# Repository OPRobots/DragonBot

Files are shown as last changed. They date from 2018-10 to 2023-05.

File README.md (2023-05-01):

# DragonBot
Robot siguelineas con succión centrifuga y STM32F1
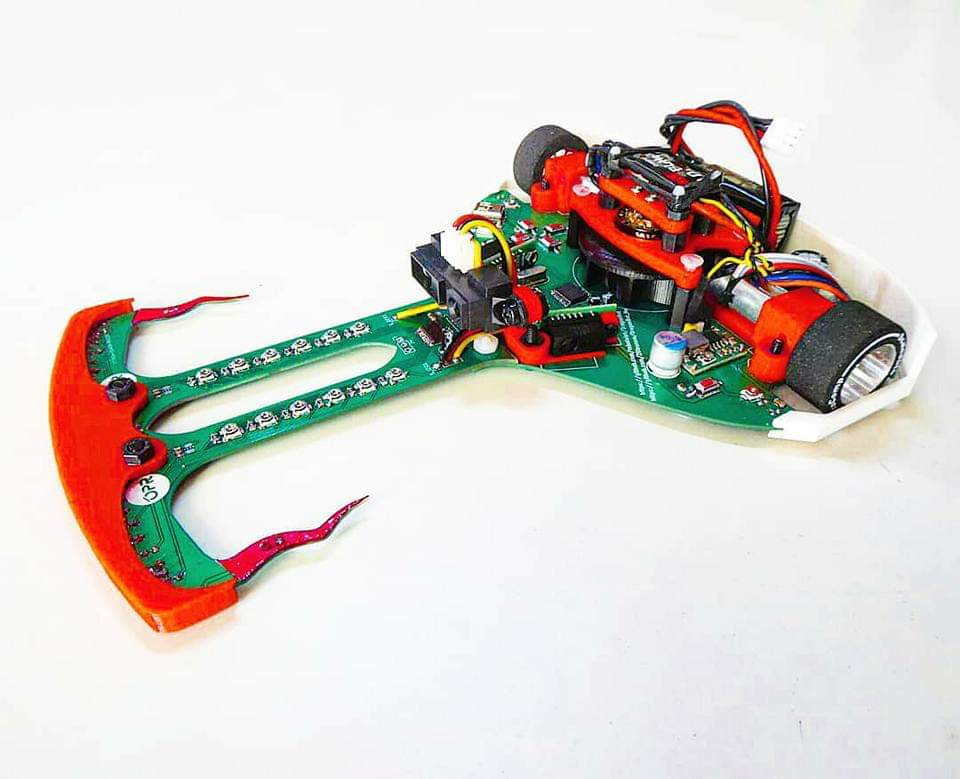
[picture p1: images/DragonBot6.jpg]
DragonBot


## Hardware
- STM32F1 "BluePill"
- Driver de motores TB6612FNG
- 2x Motores Pololu N20 HP @3000rpm
- 1x Motor Brushless Rotorx
- LiPo 2S ~250 mAh
- 12x Sensores QRE1113
- 12x Potenciometros para regular la ganancia de los sensores
- Ruedas Scaleauto Procomp 1
- Chasis de PCB autosoportado con soportes de motores, ventilador y parachoques impresos en PLA
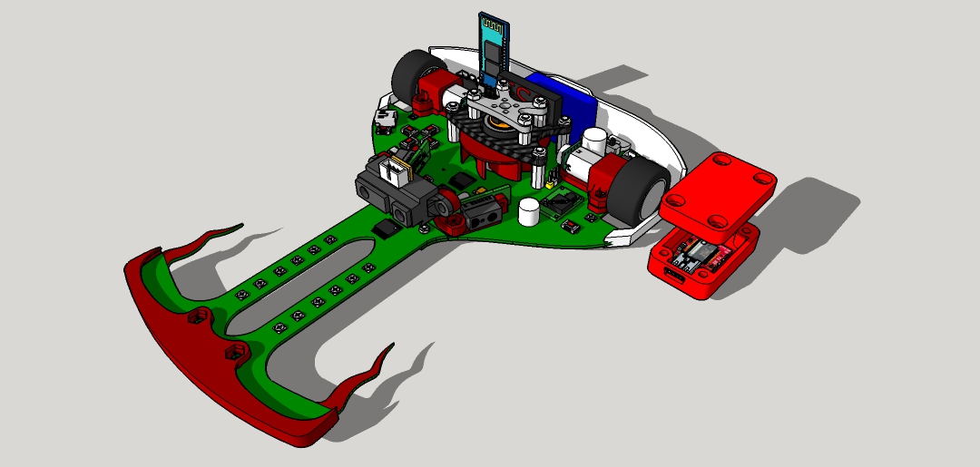
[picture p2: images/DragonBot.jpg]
DragonBot Chasis DragonBot - Chasis


## Software
- Programado con VSCode y PlatformIO
- Funciones de PID y cálculo de posición en la línea
- Disponibles programas para configuración por defecto, coreless y brushless en diferentes ramas secundarias

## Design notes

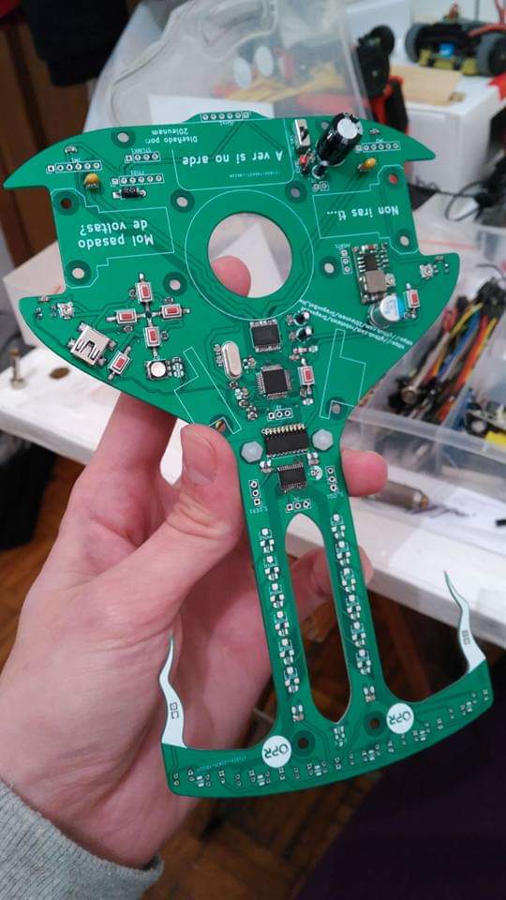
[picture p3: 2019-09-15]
images/DragonBot4.jpg

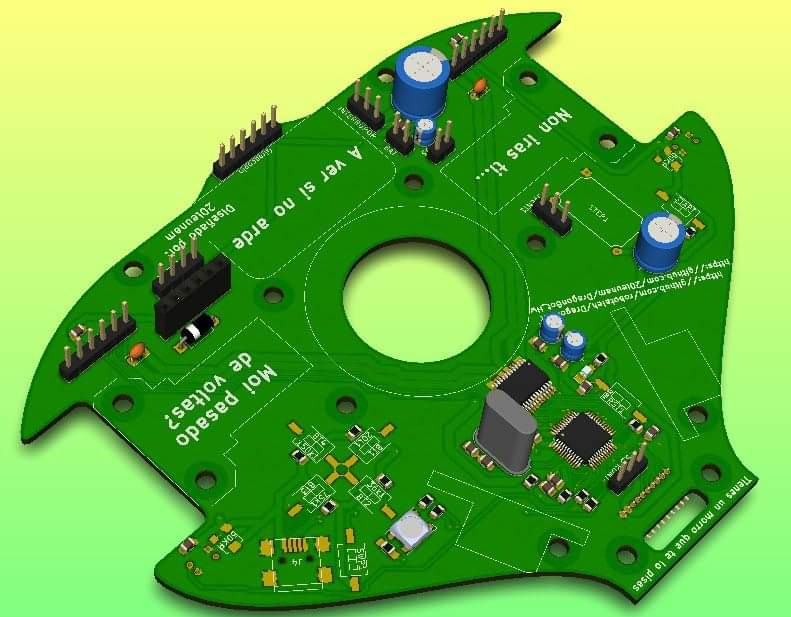
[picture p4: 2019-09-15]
images/DragonBot1.jpg

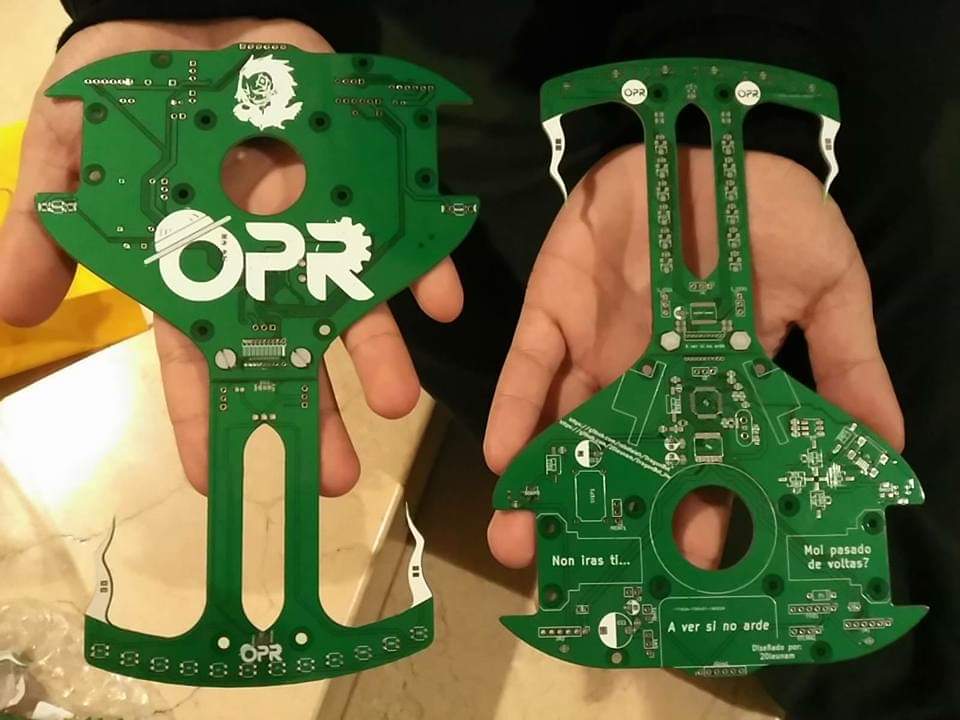
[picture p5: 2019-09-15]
images/DragonBot2.jpg

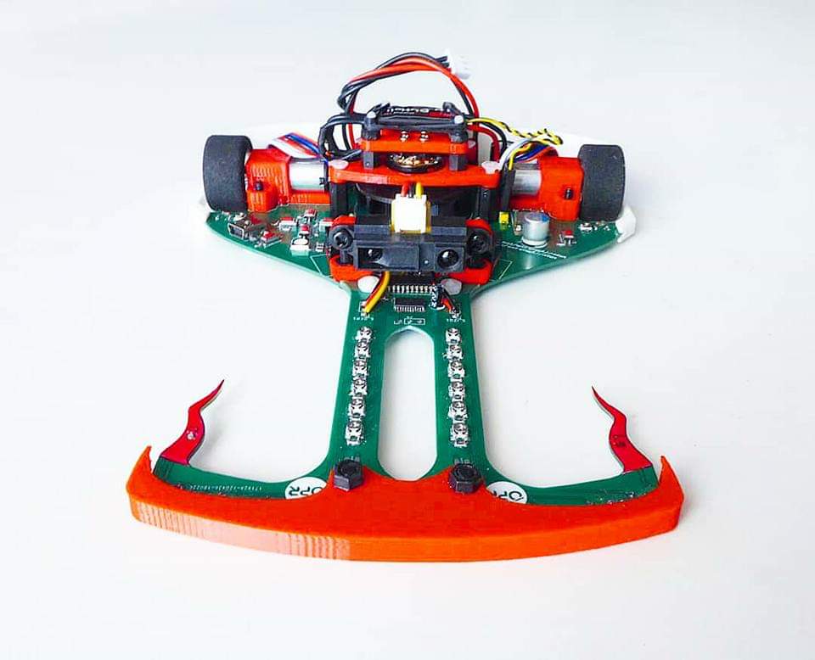
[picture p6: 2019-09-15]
images/DragonBot5.jpg

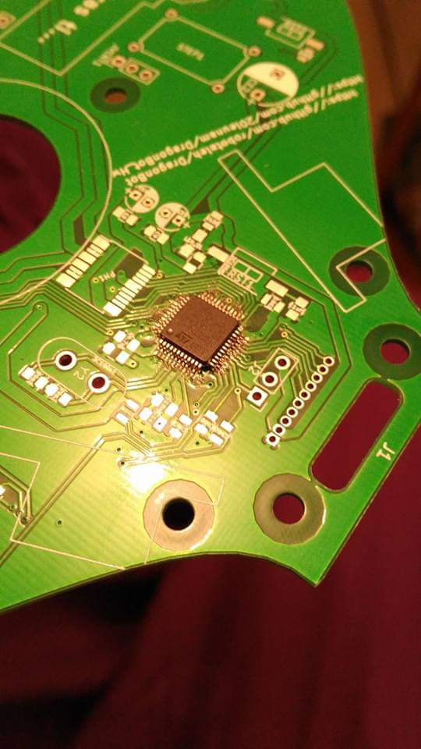
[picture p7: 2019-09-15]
images/DragonBot3.jpg

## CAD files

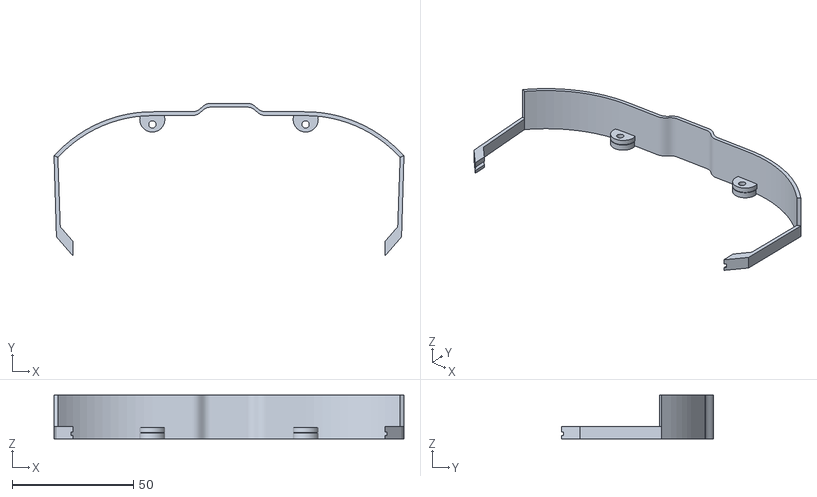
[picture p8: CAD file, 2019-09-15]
3d_model/stl_files/DragonBot_Pantalla_Trasera.stl
144.3 x 62.9 x 18.0

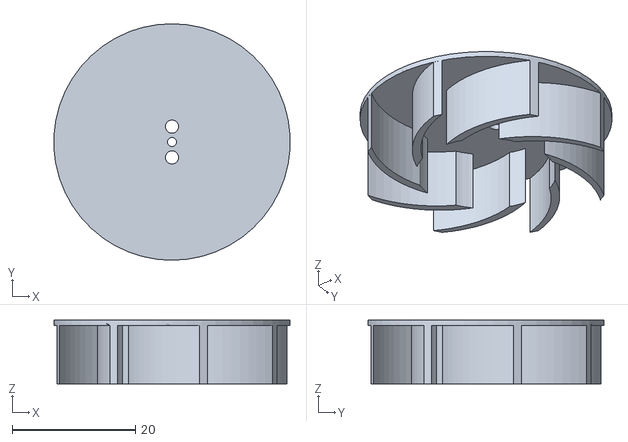
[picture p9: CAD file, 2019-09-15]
3d_model/stl_files/DragonBot_Ventilador_Succion.stl
38.3 x 38.4 x 10.4

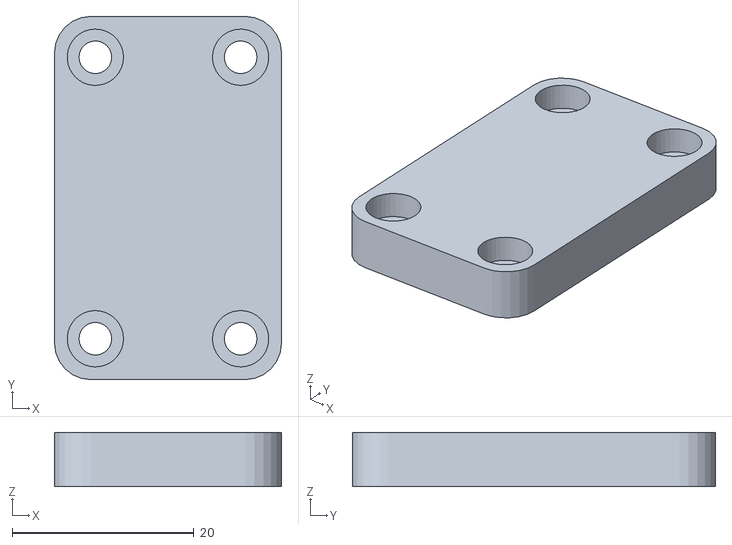
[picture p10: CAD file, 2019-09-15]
3d_model/stl_files/DragonBot_Caja_FTDI_Tapa.stl
25.0 x 40.0 x 6.00

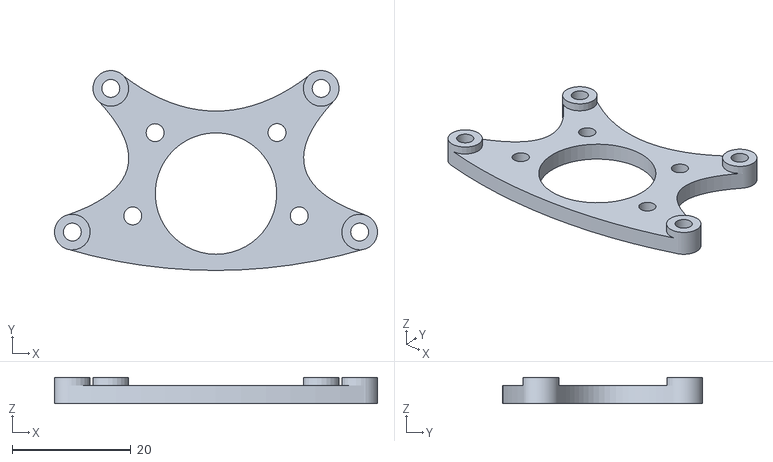
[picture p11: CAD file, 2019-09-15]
3d_model/stl_files/DragonBot_Soporte_Ventilador_Succion_Inferior.stl
54.3 x 33.6 x 4.40

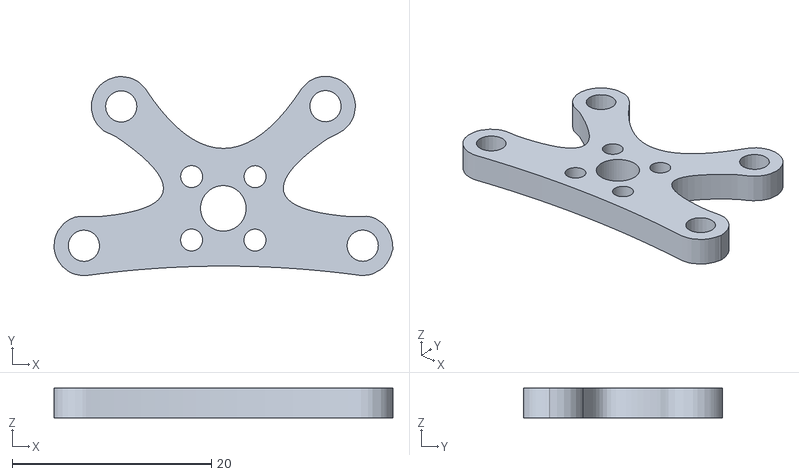
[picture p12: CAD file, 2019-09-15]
3d_model/stl_files/DragonBot_Soporte_Ventilador_Succion_Superior.stl
34.0 x 20.0 x 3.00

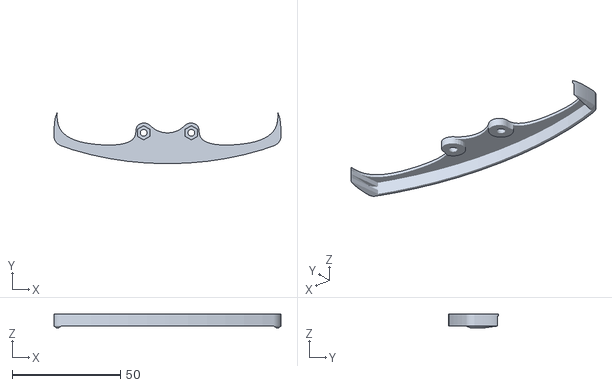
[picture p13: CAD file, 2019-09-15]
3d_model/stl_files/DragonBot_Parachoques_Morro_Ancho.stl
105.0 x 23.2 x 6.70

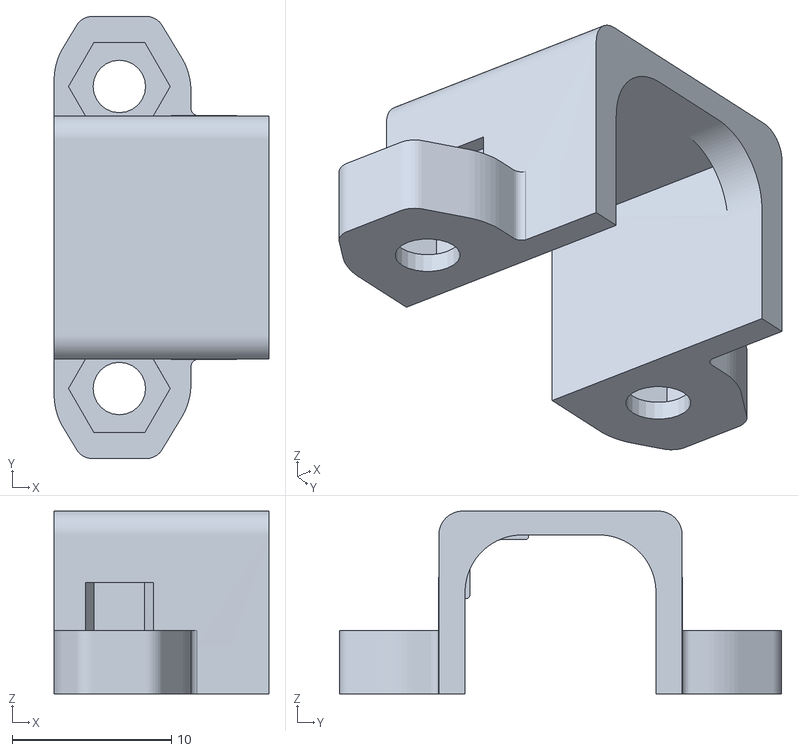
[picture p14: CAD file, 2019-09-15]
3d_model/stl_files/DragonBot_Soporte_Motor_Derecho.stl
13.5 x 27.8 x 11.5

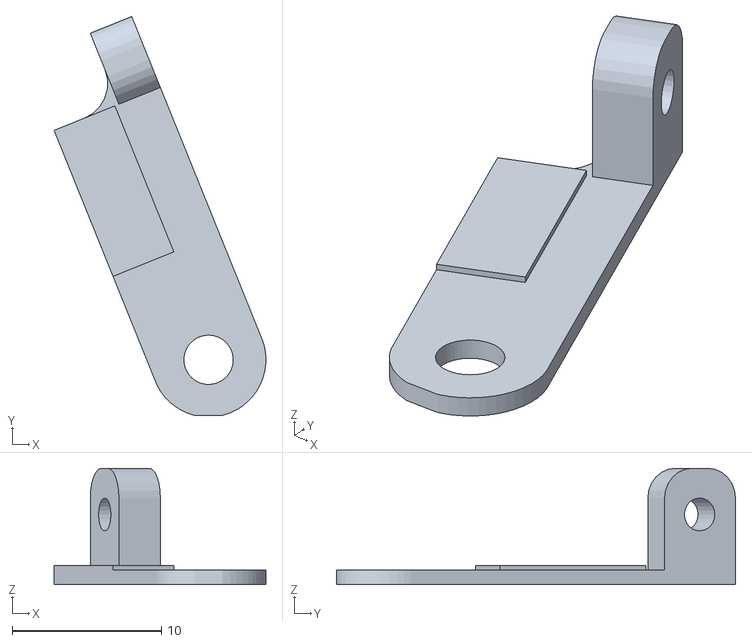
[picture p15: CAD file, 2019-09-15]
3d_model/stl_files/DragonBot_Soporte_Sensor_Lateral_Derecho.stl
14.2 x 26.8 x 7.81

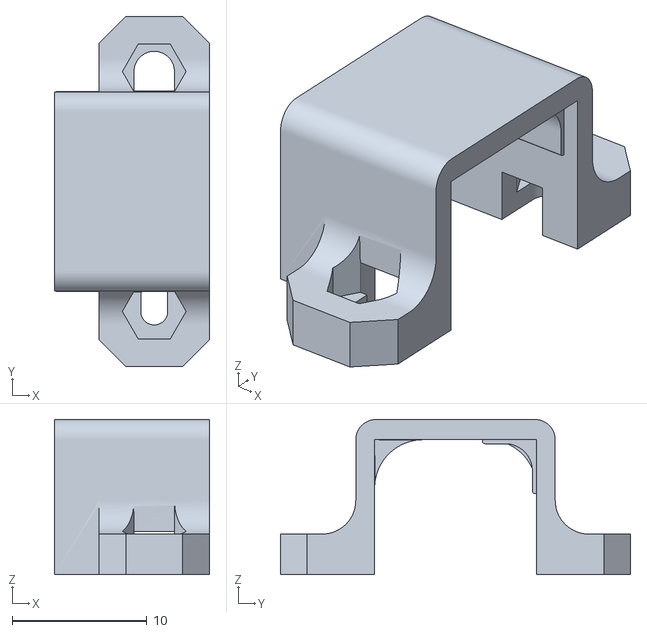
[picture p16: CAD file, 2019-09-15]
3d_model/stl_files/DragonBot_Soporte_Motor_Izquierdo.stl
11.5 x 26.0 x 11.5

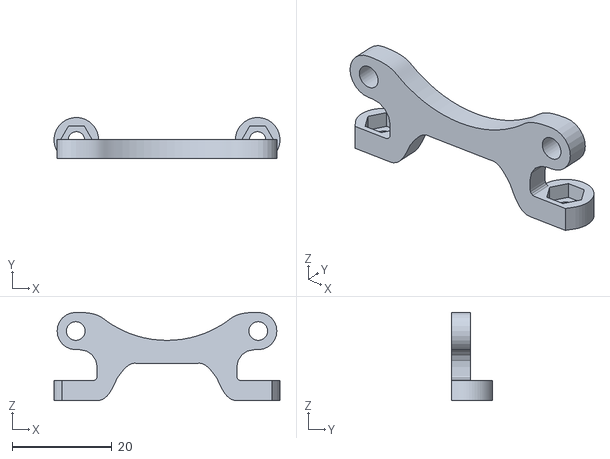
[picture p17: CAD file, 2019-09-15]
3d_model/stl_files/DragonBot_Soporte_Sensor_Frontal.stl
45.4 x 8.23 x 17.7

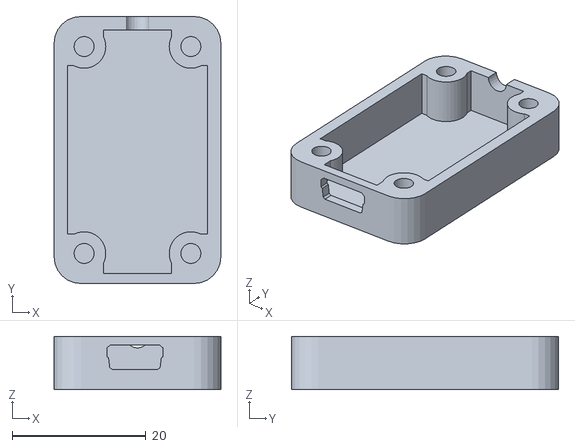
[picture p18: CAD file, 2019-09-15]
3d_model/stl_files/DragonBot_Caja_FTDI_Base.stl
25.0 x 40.0 x 8.00

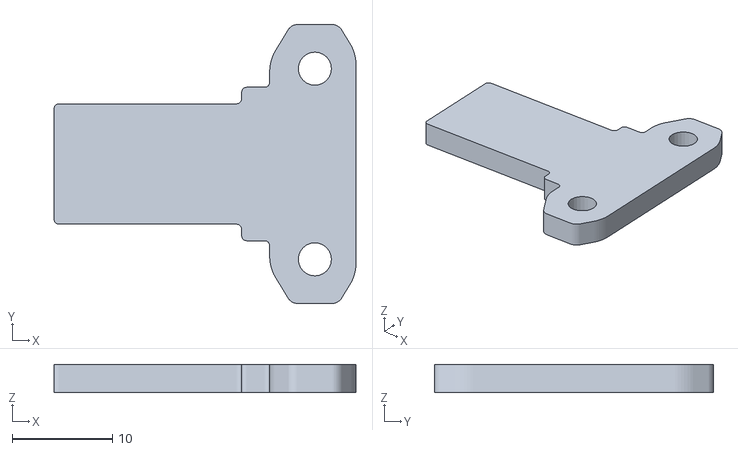
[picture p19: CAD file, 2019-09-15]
3d_model/stl_files/DragonBot_Base_Motores.stl
30.1 x 27.8 x 2.80

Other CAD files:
3d_model/stl_files/DragonBot_Soporte_Sensor_Lateral_Izquierdo.stl

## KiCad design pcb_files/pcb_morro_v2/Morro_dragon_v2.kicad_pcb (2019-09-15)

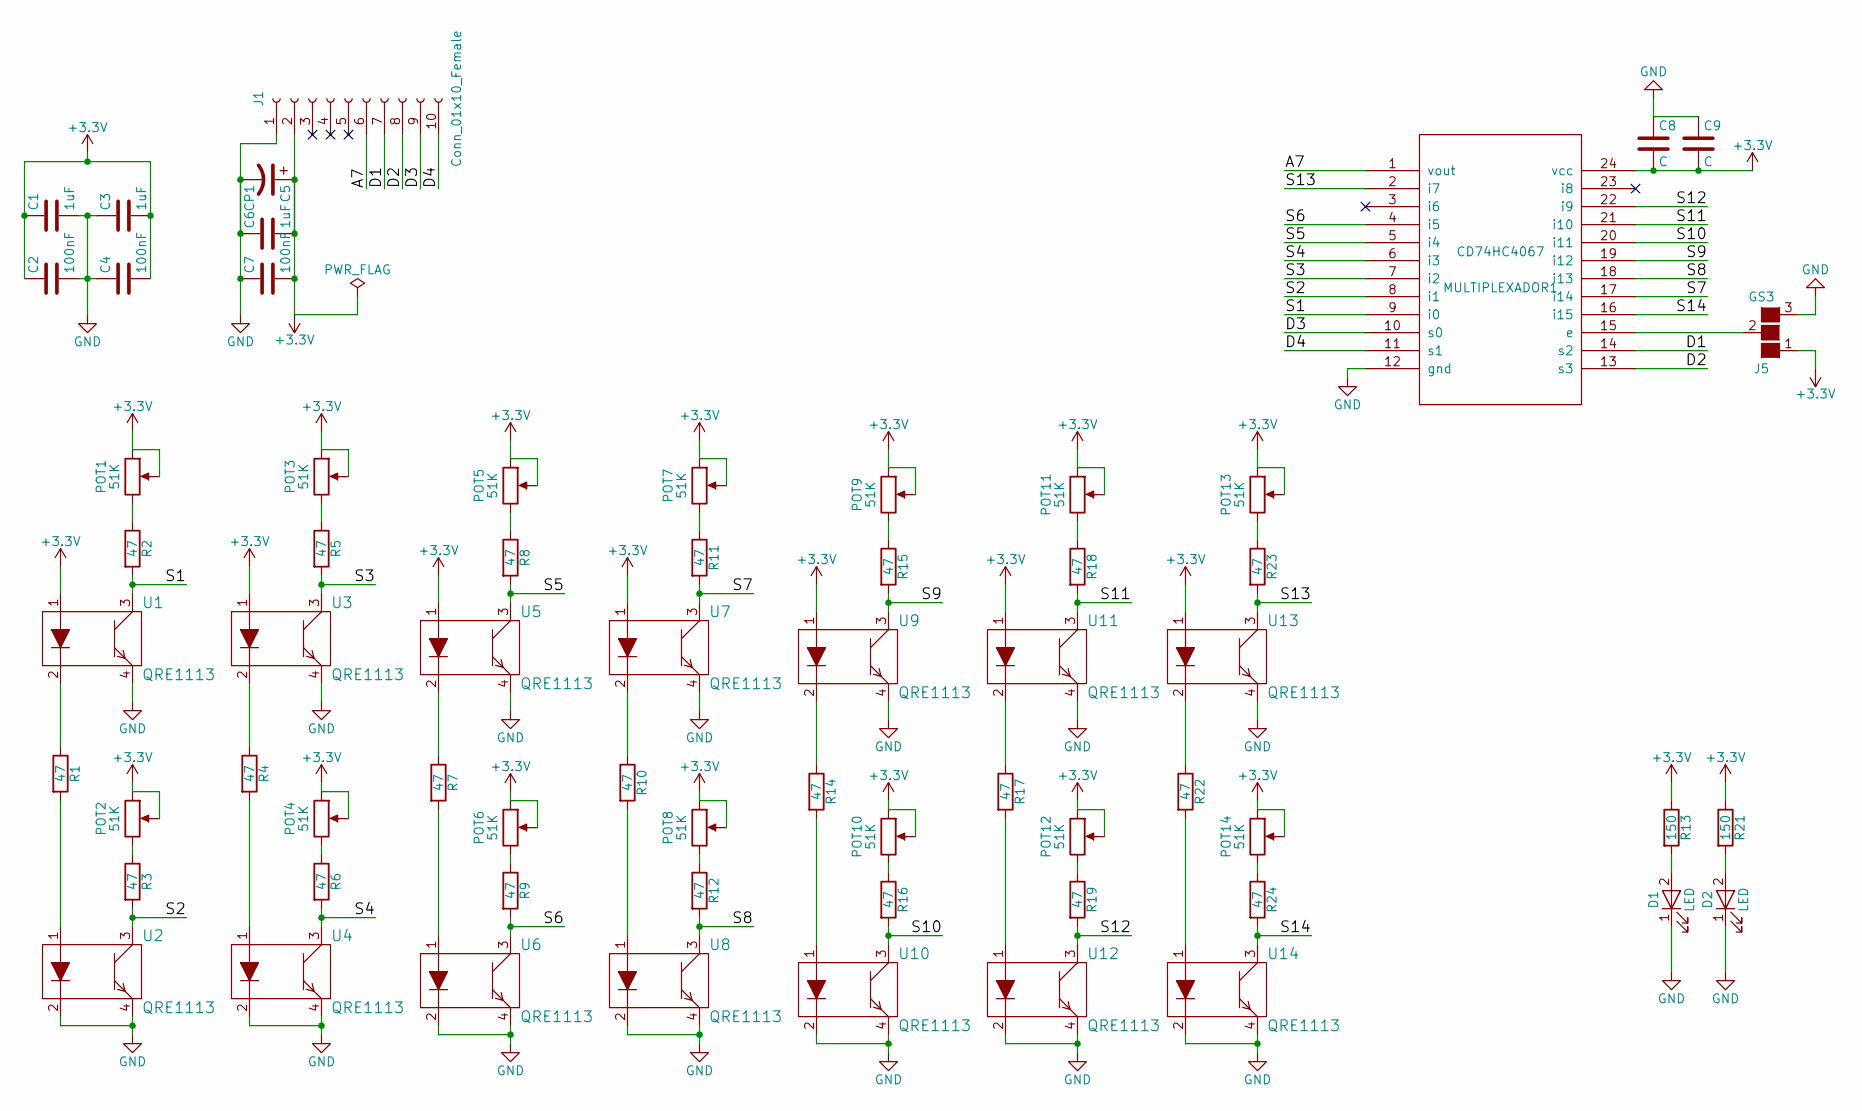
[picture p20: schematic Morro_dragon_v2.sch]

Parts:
C1, C3, C6: 1uF; C_0805
C2, C4, C7: 100nF; C_0805
C5: CP1; CP_Radial_D4.0mm_P1.50mm
C8, C9: C; C_0805
D1, D2: LED; LED_0805
J1: Conn_01x10_Female; Socket_Strip_Straight_1x10_Pitch1.27mm
J5: GS3
MULTIPLEXADOR1: CD74HC4067; TSSOP-24_4.4x7.8mm_Pitch0.65mm
POT1, POT2, POT3, POT4, POT5, POT6, POT7, POT8, POT9, POT10, POT11, POT12, POT13, POT14: 51K; Potentiometer_Trimmer-EVM3E
R1, R2, R3, R4, R5, R6, R7, R8, R9, R10, R11, R12, R14, R15, R16, R17, R18, R19, R22, R23, R24: 47; R_0805
R13, R21: 150; R_0805
U1, U2, U3, U4, U5, U6, U7, U8, U9, U10, U11, U12, U13, U14: QRE1113

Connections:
+3V3: C1.1, C2.1, C3.2, C4.2, C5.1, C6.2, C7.2, C8.2, C9.2, J1.2, J5.1 (G1), MULTIPLEXADOR1.24 (vcc), POT1.1, POT1.2, POT2.1, POT2.2, POT3.1, POT3.2, POT4.1, POT4.2, POT5.1, POT5.2, POT6.1, POT6.2, POT7.1, POT7.2, POT8.1, POT8.2, POT9.1, POT9.2, POT10.1, POT10.2, POT11.1, POT11.2, POT12.1, POT12.2, POT13.1, POT13.2, POT14.1, POT14.2, R13.1, R21.1, U1.1, U3.1, U5.1, U7.1, U9.1, U11.1, U13.1
/A7: J1.6, MULTIPLEXADOR1.1 (vout)
/D1: J1.7, MULTIPLEXADOR1.14 (s2)
/D2: J1.8, MULTIPLEXADOR1.13 (s3)
/D3: J1.9, MULTIPLEXADOR1.10 (s0)
/D4: J1.10, MULTIPLEXADOR1.11 (s1)
/S1: MULTIPLEXADOR1.9 (i0), R2.2, U1.3
/S2: MULTIPLEXADOR1.8 (i1), R3.2, U2.3
/S3: MULTIPLEXADOR1.7 (i2), R5.2, U3.3
/S4: MULTIPLEXADOR1.6 (i3), R6.2, U4.3
/S5: MULTIPLEXADOR1.5 (i4), R8.2, U5.3
/S6: MULTIPLEXADOR1.4 (i5), R9.2, U6.3
/S7: MULTIPLEXADOR1.17 (i14), R11.2, U7.3
/S8: MULTIPLEXADOR1.18 (i13), R12.2, U8.3
/S9: MULTIPLEXADOR1.19 (i12), R15.2, U9.3
/S10: MULTIPLEXADOR1.20 (i11), R16.2, U10.3
/S11: MULTIPLEXADOR1.21 (i10), R18.2, U11.3
/S12: MULTIPLEXADOR1.22 (i9), R19.2, U12.3
/S13: MULTIPLEXADOR1.2 (i7), R23.2, U13.3
/S14: MULTIPLEXADOR1.16 (i15), R24.2, U14.3
GND: C1.2, C2.2, C3.1, C4.1, C5.2, C6.1, C7.1, C8.1, C9.1, D1.1 (K), D2.1 (K), J1.1, J5.3 (G3), MULTIPLEXADOR1.12 (gnd), U1.4, U2.2, U2.4, U3.4, U4.2, U4.4, U5.4, U6.2, U6.4, U7.4, U8.2, U8.4, U9.4, U10.2, U10.4, U11.4, U12.2, U12.4, U13.4, U14.2, U14.4
unnamed: D1.2 (A), R13.2
unnamed: D2.2 (A), R21.2
unnamed: J5.2 (G2), MULTIPLEXADOR1.15 (e)
unnamed: POT1.3, R2.1
unnamed: POT2.3, R3.1
unnamed: POT3.3, R5.1
unnamed: POT4.3, R6.1
unnamed: POT5.3, R8.1
unnamed: POT6.3, R9.1
unnamed: POT7.3, R11.1
unnamed: POT8.3, R12.1
unnamed: POT9.3, R15.1
unnamed: POT10.3, R16.1
unnamed: POT11.3, R18.1
unnamed: POT12.3, R19.1
unnamed: POT13.3, R23.1
unnamed: POT14.3, R24.1
unnamed: R1.1, U1.2
unnamed: R1.2, U2.1
unnamed: R4.1, U3.2
unnamed: R4.2, U4.1
unnamed: R7.1, U5.2
unnamed: R7.2, U6.1
unnamed: R10.1, U7.2
unnamed: R10.2, U8.1
unnamed: R14.1, U9.2
unnamed: R14.2, U10.1
unnamed: R17.1, U11.2
unnamed: R17.2, U12.1
unnamed: R22.1, U13.2
unnamed: R22.2, U14.1

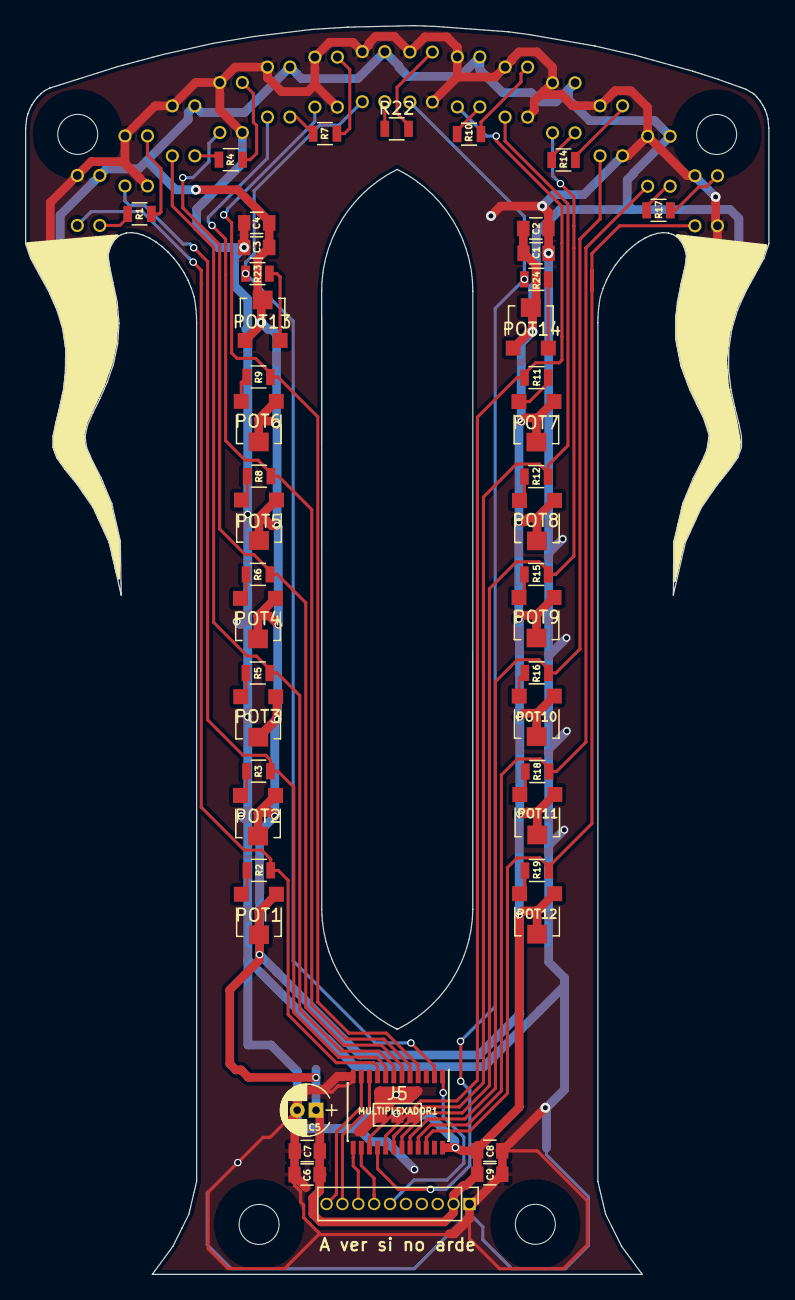
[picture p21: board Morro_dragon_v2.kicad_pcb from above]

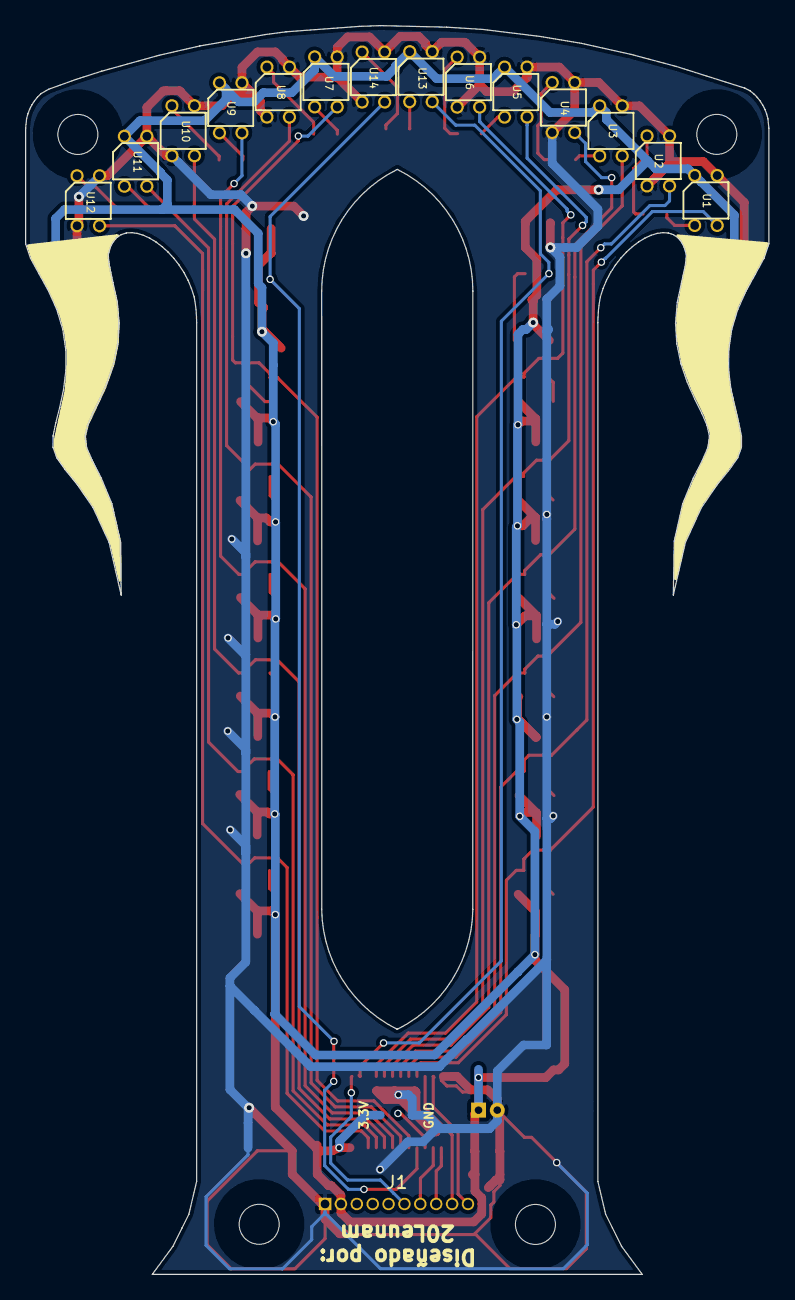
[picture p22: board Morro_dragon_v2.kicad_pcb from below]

Board: 2 copper layers, 59.4 x 99.9 mm, 65 parts (16 on the bottom side), 52 nets.

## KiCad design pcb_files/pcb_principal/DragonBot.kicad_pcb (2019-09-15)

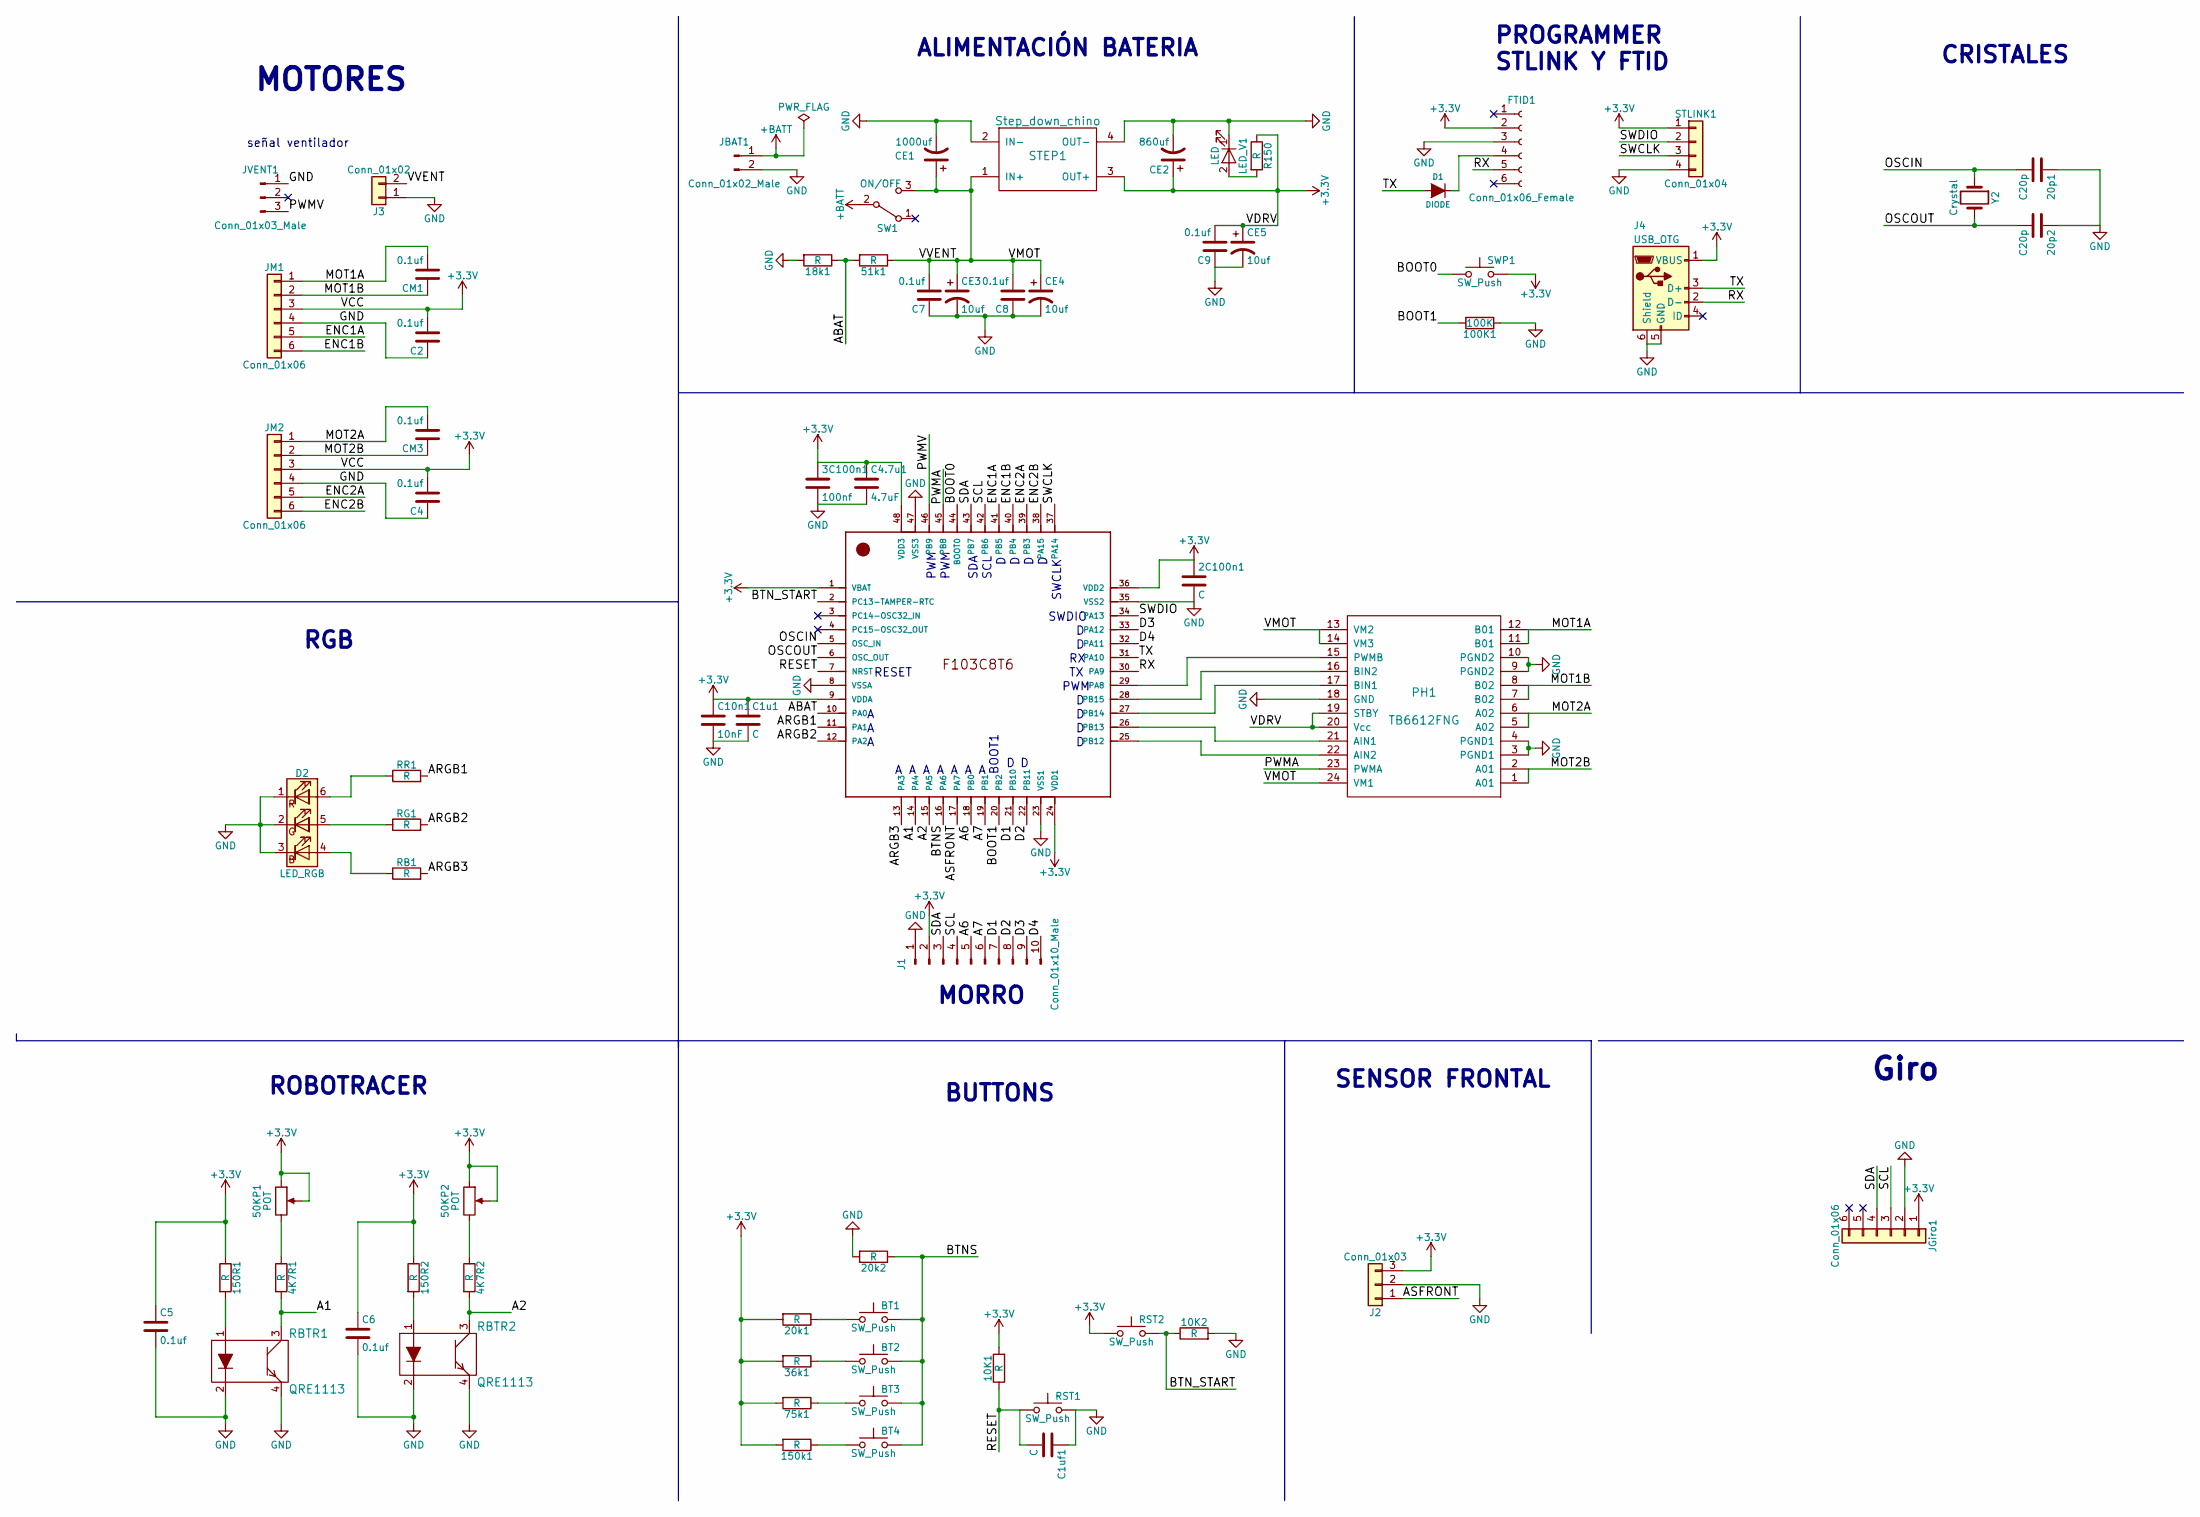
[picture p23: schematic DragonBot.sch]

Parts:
2C100n1: C; C_0805
3C100n1: 100nf; C_0805
4K7R1, 4K7R2, 10K1, 10K2, 18k1, 20k1, 20k2, 36k1, 51k1, 75k1, 150R1, 150R2, 150k1: R; R_0805
20p1, 20p2: C20p; C_0805
50KP1, 50KP2: POT; Potentiometer_Trimmer-EVM3E
100K1: 100K; R_0805
BT1, BT2, BT3, BT4: SW_Push; SW_DIP_x1_W8.61mm_Slide_LowProfile
C1u1, C1uf1: C; C_0805
C2, C4, C5, C6, C7, C8, C9: 0.1uf; C_0805
C4.7u1: 4.7uF; C_0805
C10n1: 10nF; C_0805
CE1: 1000uf; CP_Radial_D10.0mm_P7.50mm
CE2: 860uf; CP_Radial_D8.0mm_P5.00mm
CE3, CE4, CE5: 10uf; CP_Radial_D4.0mm_P2.00mm
CM1, CM3: 0.1uf; C_Disc_D3.4mm_W2.1mm_P2.50mm
D1: DIODE; D_A-405_P7.62mm_Horizontal
D2: LED_RGB; LED_RGB_5050-6
FTID1: Conn_01x06_Female; Socket_Strip_Straight_1x06_Pitch2.54mm
J1: Conn_01x10_Male; Pin_Header_Angled_1x10_Pitch1.27mm
J2: Conn_01x03; Pin_Header_Straight_1x03_Pitch2.54mm
J3: Conn_01x02; Pin_Header_Straight_1x02_Pitch2.54mm
J4: USB_OTG; USB_Mini-B
JBAT1: Conn_01x02_Male; Pin_Header_Straight_1x02_Pitch2.54mm
JGiro1: Conn_01x06; Pin_Header_Straight_1x06_Pitch2.54mm
JM1, JM2: Conn_01x06; Pin_Header_Straight_1x06_Pitch2.54mm
JVENT1: Conn_01x03_Male; Pin_Header_Straight_1x03_Pitch2.54mm
LED_V1: LED; LED_0805_HandSoldering
PH1: TB6612FNG; SSOP-24_5.3x8.2mm_Pitch0.65mm
R150: R; R_0805
RB1: R; R_0805
RBTR1, RBTR2: QRE1113
RG1: R; R_0805
RR1: R; R_0805
RST1, RST2: SW_Push; SW_DIP_x1_W8.61mm_Slide_LowProfile
STEP1: Step_down_chino
STLINK1: Conn_01x04; Pin_Header_Straight_1x04_Pitch2.54mm
SW1: ON/OFF; Pin_Header_Straight_1x03_Pitch2.54mm
SWP1: SW_Push; SW_DIP_x1_W8.61mm_Slide_LowProfile
U1: STM32F103C8T6; LQFP-48_7x7mm_Pitch0.5mm; Digi-Key_Part_Number 497-6063-ND
Y2: Crystal; Crystal_HC50_Vertical

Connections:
+3V3: 2C100n1.1, 3C100n1.1, 10K1.2, 20k1.2, 36k1.2, 50KP1.1, 50KP1.2, 50KP2.1, 50KP2.2, 75k1.2, 150R1.1, 150R2.1, 150k1.2, C1u1.1, C2.2, C4.2, C4.7u1.1, C5.1, C6.1, C9.2, C10n1.1, CE2.1, CE5.1, FTID1.2, J1.2, J2.3, J4.1 (VBUS), JGiro1.1, JM1.3, JM2.3, PH1.19 (STBY), PH1.20 (Vcc), R150.1, RST2.1, STEP1.3 (OUT+), STLINK1.1, SWP1.2, U1.1 (VBAT), U1.9 (VDDA), U1.24 (VDD1), U1.36 (VDD2), U1.48 (VDD3)
+BATT: JBAT1.1, SW1.2 (B)
/A1: 4K7R1.2, RBTR1.3, U1.14 (PA4)
/A2: 4K7R2.2, RBTR2.3, U1.15 (PA5)
/A6: J1.5, U1.18 (PB0)
/A7: J1.6, U1.19 (PB1)
/ABAT: 18k1.1, 51k1.2, U1.10 (PA0)
/ARGB1: RR1.2, U1.11 (PA1)
/ARGB2: RG1.2, U1.12 (PA2)
/ARGB3: RB1.2, U1.13 (PA3)
/ASFRONT: J2.1, U1.17 (PA7)
/BOOT0: SWP1.1, U1.44 (BOOT0)
/BOOT1: 100K1.2, U1.20 (PB2)
/BTNS: 20k2.1, BT1.2, BT2.2, BT3.2, BT4.2, U1.16 (PA6)
/BTN_START: 10K2.1, RST2.2, U1.2 (PC13-TAMPER-RTC)
/D1: J1.7, U1.21 (PB10)
/D2: J1.8, U1.22 (PB11)
/D3: J1.9, U1.33 (PA12)
/D4: J1.10, U1.32 (PA11)
/ENC1A: JM1.5, U1.41 (PB5)
/ENC1B: JM1.6, U1.40 (PB4)
/ENC2A: JM2.5, U1.39 (PB3)
/ENC2B: JM2.6, U1.38 (PA15)
/MOT1A: CM1.2, JM1.1, PH1.11 (B01), PH1.12 (B01)
/MOT1B: CM1.1, JM1.2, PH1.7 (B02), PH1.8 (B02)
/MOT2A: CM3.2, JM2.1, PH1.5 (A02), PH1.6 (A02)
/MOT2B: CM3.1, JM2.2, PH1.1 (A01), PH1.2 (A01)
/OSCIN: 20p1.2, U1.5 (OSC_IN), Y2.1
/OSCOUT: 20p2.2, U1.6 (OSC_OUT), Y2.2
/PWMA: PH1.23 (PWMA), U1.45 (PB8)
/PWMV: JVENT1.3, U1.46 (PB9)
/RESET: 10K1.1, C1uf1.2, RST1.1, U1.7 (NRST)
/RX: FTID1.5, J4.2 (D-), U1.30 (PA9)
/SCL: J1.4, JGiro1.3, U1.42 (PB6)
/SDA: J1.3, JGiro1.4, U1.43 (PB7)
/SWCLK: STLINK1.3, U1.37 (PA14)
/SWDIO: STLINK1.2, U1.34 (PA13)
/TX: D1.1 (A), J4.3 (D+), U1.31 (PA10)
/VMOT: 51k1.1, C7.2, C8.2, CE1.1, CE3.1, CE4.1, J3.2, PH1.13 (VM2), PH1.14 (VM3), PH1.24 (VM1), STEP1.1 (IN+), SW1.3 (C)
GND: 2C100n1.2, 3C100n1.2, 10K2.2, 18k1.2, 20k2.2, 20p1.1, 20p2.1, 100K1.1, C1u1.2, C1uf1.1, C2.1, C4.1, C4.7u1.2, C5.2, C6.2, C7.1, C8.1, C9.1, C10n1.2, CE1.2, CE2.2, CE3.2, CE4.2, CE5.2, D2.1 (RK), D2.2 (GK), D2.3 (BK), FTID1.3, J1.1, J2.2, J3.1, J4.5 (GND), J4.6 (Shield), JBAT1.2, JGiro1.2, JM1.4, JM2.4, JVENT1.1, LED_V1.1 (K), PH1.3 (PGND1), PH1.4 (PGND1), PH1.9 (PGND2), PH1.10 (PGND2), PH1.18 (GND), RBTR1.2, RBTR1.4, RBTR2.2, RBTR2.4, RST1.2, STEP1.2 (IN-), STEP1.4 (OUT-), STLINK1.4, U1.8 (VSSA), U1.23 (VSS1), U1.35 (VSS2), U1.47 (VSS3)
unnamed: 4K7R1.1, 50KP1.3
unnamed: 4K7R2.1, 50KP2.3
unnamed: 20k1.1, BT1.1
unnamed: 36k1.1, BT2.1
unnamed: 75k1.1, BT3.1
unnamed: 150R1.2, RBTR1.1
unnamed: 150R2.2, RBTR2.1
unnamed: 150k1.1, BT4.1
unnamed: D1.2 (K), FTID1.4
unnamed: D2.4 (BA), RB1.1
unnamed: D2.5 (GA), RG1.1
unnamed: D2.6 (RA), RR1.1
unnamed: LED_V1.2 (A), R150.2
unnamed: PH1.15 (PWMB), U1.29 (PA8)
unnamed: PH1.16 (BIN2), U1.28 (PB15)
unnamed: PH1.17 (BIN1), U1.27 (PB14)
unnamed: PH1.21 (AIN1), U1.26 (PB13)
unnamed: PH1.22 (AIN2), U1.25 (PB12)

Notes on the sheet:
RGB
ROBOTRACER
BUTTONS
MORRO
PROGRAMMER STLINK Y FTID
MOTORES
ALIMENTACIÓN BATERIA
CRISTALES
señal ventilador
SENSOR FRONTAL
SWDIO
RESET
BOOT1
PWM
SDA
SCL
SWCLK
Giro

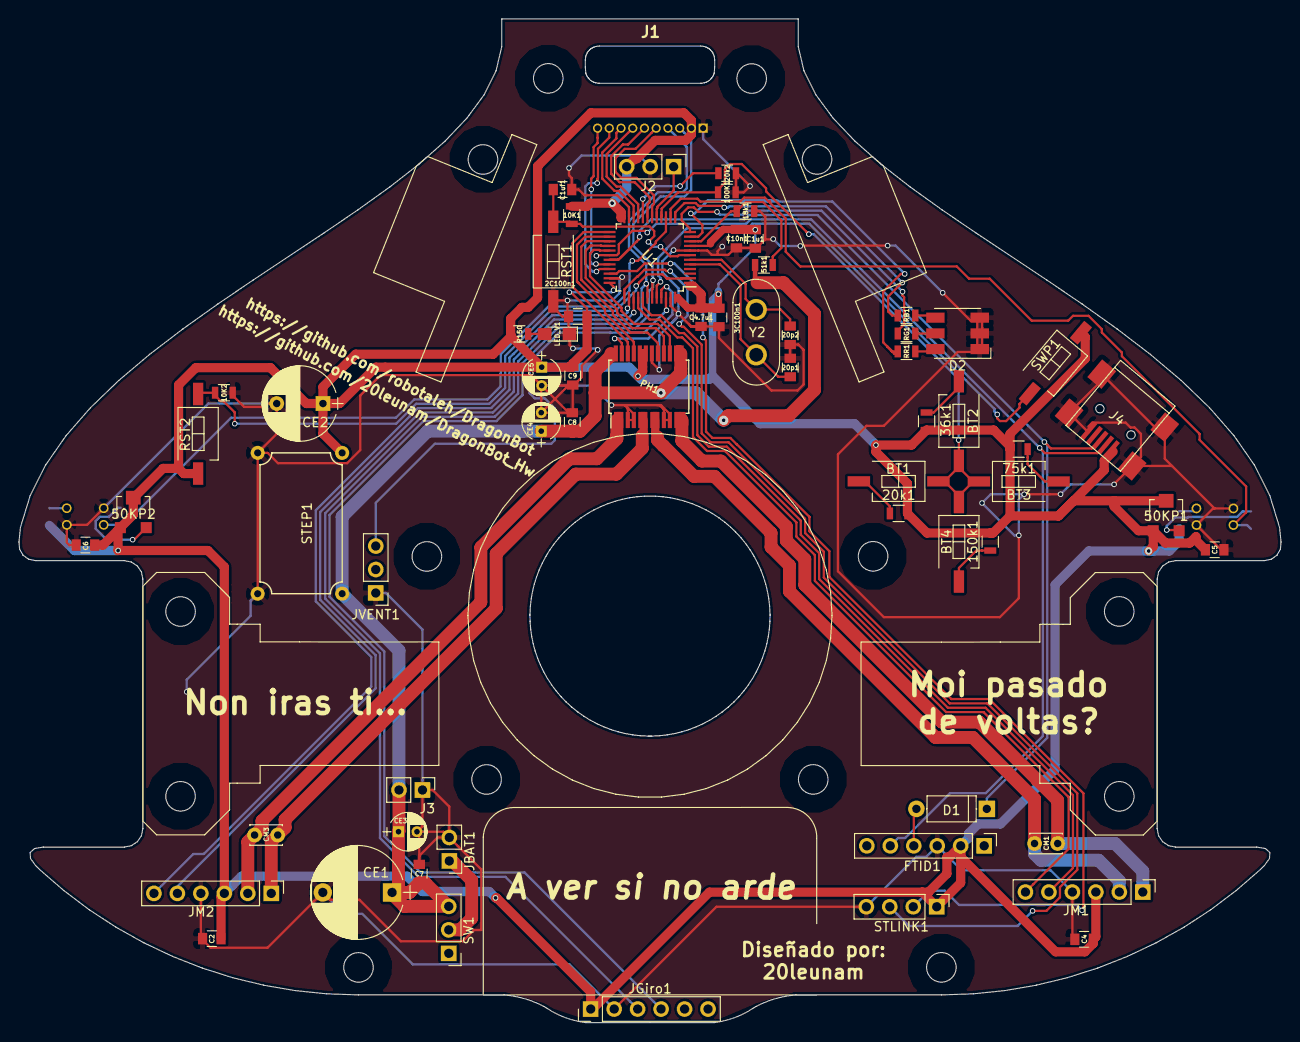
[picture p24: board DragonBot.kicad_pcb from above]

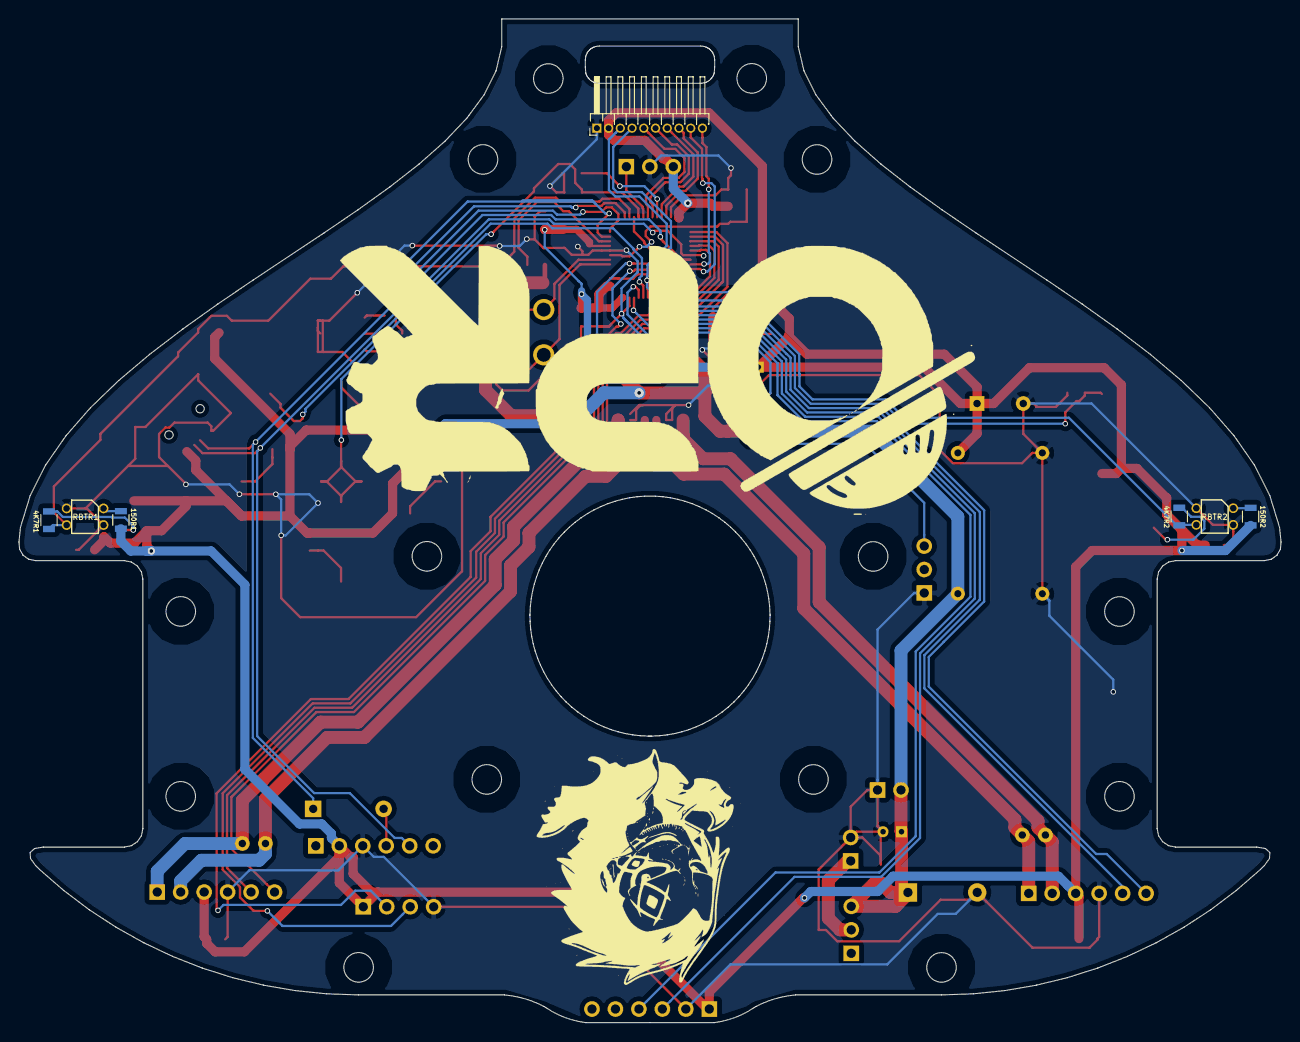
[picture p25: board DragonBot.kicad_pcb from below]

Board: 2 copper layers, 136.6 x 108.6 mm, 70 parts (7 on the bottom side), 58 nets.

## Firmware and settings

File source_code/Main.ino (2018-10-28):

//////////////////////////
// INCLUDE de LIBRERIAS //
//////////////////////////
/**
 * Calibración del PID desde la APP android PIDfromBT
 * https://github.com/robotaleh/PIDfromBT
 */
#include <Filter.h>
#include <MegunoLink.h>
#include <PIDfromBT.h>
#include <Wire.h>

////////////////////////
// SELECTOR DE ROBOT  //
////////////////////////
// #define DRAGON_A 1
#define DRAGON_B 1

#define MORRO_ANCHO 1
// #define MORRO_ESTRECHO 1

////////////
// MODOS  //
////////////
#define MODO_LINEA 1

#define LINEA_NEGRA 1
#define LINEA_BLANCA 2

#define LIPO_2S 1
#define LIPO_3S 2

///////////////////
// CONFIGURACION //
///////////////////
#define MILLIS_INICIO 2000
#define PISTA MODO_LINEA
#define LINEA LINEA_NEGRA
#define LIPO LIPO_3S
#define TIEMPO_CALIBRADO 2500
#define CALIBRAR_SENSORES true

//////////////
// SENSORES //
//////////////
#define TIEMPO_SIN_PISTA 200

#ifdef MORRO_ANCHO
#define NUMERO_SENSORES 8
#define SENSOR_1 0
#define SENSOR_2 1
#define SENSOR_3 2
#define SENSOR_4 3
#define SENSOR_5 4
#define SENSOR_6 5
#define SENSOR_7 14
#define SENSOR_8 13
#define SENSOR_9 12
#define SENSOR_10 11
#define SENSOR_11 10
#define SENSOR_12 9

#elif MORRO_ESTRECHO
#define NUMERO_SENSORES 14
#define SENSOR_1 0
#define SENSOR_2 1
#define SENSOR_3 2
#define SENSOR_4 3
#define SENSOR_5 4
#define SENSOR_6 5
#define SENSOR_7 7
#define SENSOR_8 15
#define SENSOR_9 14
#define SENSOR_10 13
#define SENSOR_11 12
#define SENSOR_12 11
#define SENSOR_13 10
#define SENSOR_14 9
#endif
#define SENSOR_ROBOTRACER_DERECHO PA4
#define SENSOR_ROBOTRACER_IZQUIERDO PA5

#define CALIBRADO_MAXIMO_SENSORES_LINEA 4000
#define CALIBRADO_MINIMO_SENSORES_LINEA 0
#define SATURACION_MAXIMO_SENSORES_LINEA 3000
#define SATURACION_MINIMO_SENSORES_LINEA 1000

///////////////////
// MULTIPLEXADOR //
///////////////////
#define MUX_LECTURA PB1
#define MUX_CANAL_0 PA12
#define MUX_CANAL_1 PA11
#define MUX_CANAL_2 PB10
#define MUX_CANAL_3 PB11

/////////////
// MOTORES //
/////////////
#ifdef DRAGON_A
#define MOTOR_DERECHO_ADELANTE PB15
#define MOTOR_DERECHO_ATRAS PB14
#define MOTOR_IZQUIERDO_ADELANTE PB13
#define MOTOR_IZQUIERDO_ATRAS PB12
#endif

#ifdef DRAGON_B
#define MOTOR_DERECHO_ADELANTE PB14
#define MOTOR_DERECHO_ATRAS PB15
#define MOTOR_IZQUIERDO_ADELANTE PB13
#define MOTOR_IZQUIERDO_ATRAS PB12
#endif

#define MOTOR_DERECHO_PWM PA8
#define MOTOR_IZQUIERDO_PWM PB8
#define MOTOR_SUCCION PB9

//////////////
// ENCODERS //
//////////////
#define MOTOR_DERECHO_ENCODER_A PB5
#define MOTOR_DERECHO_ENCODER_B PB4
#define MOTOR_IZQUIERDO_ENCODER_A PA15
#define MOTOR_IZQUIERDO_ENCODER_B PB3

//////////////
// MPU9250  //
//////////////
#define MPU9250_ADDRESS 0x68

#define GYRO_FULL_SCALE_250_DPS 0x00
#define GYRO_FULL_SCALE_500_DPS 0x08
#define GYRO_FULL_SCALE_1000_DPS 0x10
#define GYRO_FULL_SCALE_2000_DPS 0x18

#define ACC_FULL_SCALE_2_G 0x00
#define ACC_FULL_SCALE_4_G 0x08
#define ACC_FULL_SCALE_8_G 0x10
#define ACC_FULL_SCALE_16_G 0x18

//////////
// LEDS //
//////////
#define RED_RGB_R PA1
#define RED_RGB_G PA2
#define RED_RGB_B PA3

///////////////////////////////////
// VARIABLES DE CONTROL DE LEDS  //
///////////////////////////////////
int colorRGB[] = {255, 0, 0};
int colorDesc = 0;
int colorAsc = 1;
long ultimoCambioRGB = 0;

/////////////
// BOTONES //
/////////////
#define BTN PC13
#define BTN_CRUCETA PA6

//////////
// MISC //
//////////
#define NIVEL_BATERIA PA0

///////////////
// VARIABLES //
///////////////
float anguloGiro = 0;
float anguloGiroR = 0;
float velocidadW = 0;
float velocidadMs = 0;
float posXm = 0;
float posYm = 0;
int velocidad = 0;
float velocidadMsIdeal = 0;
float velocidadMsIdealBase = 0;
int velocidadSuccion = 0;
int velocidadSuccionBase = 50;
int velocidadMaxima = 255;
long ultimaLinea = 0;
long ultimaBateria = 0;
bool avisoBateria = false;
int intervaloAvisoBateria = 500;
long millisInitESC = -1;
bool ESCIniciado = false;

//////////////////////////
// VARIABLES DE CONTROL //
//////////////////////////
int posicionActual = 0;
int posicionIdeal = 0;
int posicionIdealObjetivo;
float errorAnterior = 0;
float integralErrores = 0;
float kp;
float ki;
float kd;
float kpVelocidad = 5;
float kdVelocidad = 10;
float ultimoErrorVelocidad = 0;
int correccion = 0;

////////////////////////////
// VARIABLES DE ENCODERS  //
////////////////////////////
#define ENCODER_PPR 119
#define RUEDAS_RADIO 0.01275
float ticksMm = 1.444f;
long ticksDerechoAnteriores = 0;
long ticksIzquierdoAnteriores = 0;
volatile long ticksDerecho = 0;
volatile long ticksIzquierdo = 0;

///////////////////////////
// VARIABLES DE SENSORES //
///////////////////////////
int valorSaturacionBajo;
int valorSaturacionAlto;
#ifdef MORRO_ANCHO
int pinesSensores[] = {/* SENSOR_1, SENSOR_2, */ SENSOR_3, SENSOR_4, SENSOR_5, SENSOR_6, SENSOR_7, SENSOR_8, SENSOR_9, SENSOR_10/* , SENSOR_11, SENSOR_12 */};
int valoresSensores[] = {0, 0, 0, 0, 0, 0, 0, 0, 0, 0, 0, 0};
int valoresSensoresRaw[] = {0, 0, 0, 0, 0, 0, 0, 0, 0, 0, 0, 0};
#elif MORRO_ESTRECHO
int pinesSensores[] = {SENSOR_1, SENSOR_2, SENSOR_3, SENSOR_4, SENSOR_5, SENSOR_6, SENSOR_7, SENSOR_8, SENSOR_9, SENSOR_10, SENSOR_11, SENSOR_12, SENSOR_13, SENSOR_14};
int valoresSensores[] = {0, 0, 0, 0, 0, 0, 0, 0, 0, 0, 0, 0, 0, 0};
int valoresSensoresRaw[] = {0, 0, 0, 0, 0, 0, 0, 0, 0, 0, 0, 0, 0, 0};
#endif
int posicionMaxima = 6500;
int posicionMinima = -6500;

///////////////////////////////
// VARIABLES DE CALIBRACIÓN  //
///////////////////////////////
#ifdef MORRO_ANCHO
int valoresCalibracionMinimos[] = {4096, 4096, 4096, 4096, 4096, 4096, 4096, 4096, 4096, 4096, 4096, 4096};
int valoresCalibracionMaximos[] = {0, 0, 0, 0, 0, 0, 0, 0, 0, 0, 0, 0};
#elif MORRO_ESTRECHO
int valoresCalibracionMinimos[] = {4096, 4096, 4096, 4096, 4096, 4096, 4096, 4096, 4096, 4096, 4096, 4096, 4096, 4096};
int valoresCalibracionMaximos[] = {0, 0, 0, 0, 0, 0, 0, 0, 0, 0, 0, 0, 0, 0};
#endif
int umbralesCalibracionSensores[NUMERO_SENSORES];
int valorCalibradoMaximo;
int valorCalibradoMinimo;

///////////////////////////////
// VARIABLES DE COMPETICIÓN  //
///////////////////////////////
bool competicionIniciada = false;

/////////////////////////////////////////
// VARIABLES DE MENÚ DE CONFIGURACIÓN  //
/////////////////////////////////////////
#define NUMERO_COMBINACIONES 10
#define CRUCETA_ARRIBA 1460
#define CRUCETA_ABAJO 475
#define CRUCETA_DERECHA 860
#define CRUCETA_IZQUIERDA 2040
#define CRUCETA_ARRIBA_ABAJO 1670
#define CRUCETA_DERECHA_IZQUIERDA 2280
#define CRUCETA_ARRIBA_DERECHA 1840
#define CRUCETA_DERECHA_ABAJO 1160
#define CRUCETA_ABAJO_IZQUIERDA 2170
#define CRUCETA_IZQUIERDA_ARRIBA 2490
int crucetaCombinaciones[] = {CRUCETA_ARRIBA,
                              CRUCETA_ABAJO,
                              CRUCETA_DERECHA,
                              CRUCETA_IZQUIERDA,
                              CRUCETA_ARRIBA_ABAJO,
                              CRUCETA_DERECHA_IZQUIERDA,
                              CRUCETA_ARRIBA_DERECHA,
                              CRUCETA_DERECHA_ABAJO,
                              CRUCETA_ABAJO_IZQUIERDA,
                              CRUCETA_IZQUIERDA_ARRIBA};
#define NUMERO_VELOCIDADES 9
int velocidad_menu = 0;
#define NUMERO_VELOCIDADES_SUCCION 9
int velocidad_succion_menu = 0;

//////////////////////////////
// INICIALIZACION LIBRERIAS //
//////////////////////////////
HardwareTimer TimerPID(2);
bool timerPID_pause = false;
HardwareTimer TimerBrushless(3);
PIDfromBT CalibracionPID(&kp, &ki, &kd, &velocidad, &posicionIdeal, &velocidadSuccion, DEBUG);
ExponentialFilter<long> filtroBateria(15, 0);

void setup() {
  inicia_todo();
  inicia_timer_Brushless();
  nivel_bateria(false);
  calibra_sensores();
  delay(100);
}

void loop() {
  // CalibracionPID.update();
  if (!competicionIniciada) {
    btn_cruceta();
    if (!btn_pulsado()) {
      delay(100);
      if (btn_pulsado()) {
        set_color_RGB(255, 0, 0);
        while (btn_pulsado()) {
        }
        long millisIniciales = millis();
        int tiempoPasado = 5;
        while (millis() < (millisIniciales + MILLIS_INICIO)) {
          tiempoPasado = millis() - millisIniciales;
          byte r = 0, g = 0;
          r = map(tiempoPasado, 0, MILLIS_INICIO, 255, 0);
          g = map(tiempoPasado, 0, 1000, 0, 255);
          set_color_RGB(r, g, 0);
          if ((tiempoPasado > MILLIS_INICIO * 0.75f || MILLIS_INICIO == 0) && velocidadSuccion == 0 && velocidadSuccionBase > 0) {
            velocidadSuccion = 50;
          }
        }
        ticksDerecho = 0;
        ticksIzquierdo = 0;
        ticksDerechoAnteriores = 0;
        ticksIzquierdoAnteriores = 0;
        velocidadMs = 0;
        inicia_timer_PID();
        competicionIniciada = true;
        set_color_RGB(0, 0, 0);
        velocidadMsIdeal = velocidadMsIdealBase;
        velocidadSuccion = velocidadSuccionBase;
      }
    }
  }
}

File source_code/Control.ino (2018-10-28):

/**
 * Función para controlar nivel de carga de la LiPo durante el funcionamiento
 * @param  enLoop Indica si se ha llamado a la función desde el loop, para efectuar la comprobación con intervalo
 */
void nivel_bateria(bool enLoop) {
  int carga;
  byte r, g;
  if (enLoop) {
    if (millis() > (ultimaBateria + intervaloAvisoBateria)) {
      set_color_RGB(0, 0, 0);
      switch (LIPO) {
      case LIPO_2S:
        filtroBateria.Filter(map(analogRead(NIVEL_BATERIA), 2447, 2247, 100, 0));
        break;
      case LIPO_3S:
        filtroBateria.Filter(map(analogRead(NIVEL_BATERIA), 4083, 2718, 100, 0));
        break;
      }
      carga = filtroBateria.Current();
      if (carga <= 15) {
        if (carga <= 5) {
          intervaloAvisoBateria = 100;
        } else {
          intervaloAvisoBateria = 500;
        }
        avisoBateria = !avisoBateria;
        if (avisoBateria) {
          set_color_RGB(255, 0, 0);
        } else {
          set_color_RGB(0, 0, 0);
        }
      }
      ultimaBateria = millis();
    } else {
      if (velocidad >= 255 /* && abs(velocidadMs-velocidadMsIdeal)>0.25 */) {
        if (!avisoBateria) {
          set_color_RGB(0, 255, 255);
        }
      } else {
        if (!avisoBateria) {
          set_color_RGB(0, 0, 0);
        }
      }
    }
  } else {
    filtroBateria.Filter(0);
    long millisInicial = millis();
    do {
      switch (LIPO) {
      case LIPO_2S:
        filtroBateria.Filter(map(analogRead(NIVEL_BATERIA), 2500, 2300, 100, 0));
        break;
      case LIPO_3S:
        filtroBateria.Filter(map(analogRead(NIVEL_BATERIA), 4083, 2718, 100, 0));
        break;
      }
      carga = filtroBateria.Current();
      if (carga >= 75) {
        r = 0;
        g = 255;
      } else if (carga > 50) {
        r = map(carga, 51, 100, 255, 0);
        g = 255;
      } else if (carga < 50) {
        r = 255;
        g = map(carga, 49, 0, 255, 0);
      } else {
        r = 255;
        g = 255;
      }
      delay(1);
    } while ((millis() - millisInicial) < 500);
    set_color_RGB(r, g, 0);
    delay(2000);
    set_color_RGB(0, 0, 0);
  }
}

/**
 * Función para calcular a posición para cada tipo de pista.
 * @param  ultimaPosicion Última posición calculada para usar en caso de pérdida de pista
 * @return [int]          Posición actual sobre la línea
 */
int calcular_posicion(int ultimaPosicion) {
  switch (PISTA) {
  case MODO_LINEA:
    return calcula_posicion_linea(ultimaPosicion);
    break;
  }
  return 0;
}

/**
 * Función para realizar el cálculo de la posición en base a la lectura de los sensores.
 * @param  ultimaPosicion Última posición calculada para usar en caso de pérdida de línea
 * @return [int]           Posición actual sobre la línea
 */
int calcula_posicion_linea(int ultimaPosicion) {
  lectura_sensores_calibrados();

  unsigned long sumaSensoresPonderados = 0;
  unsigned long sumaSensores = 0;
  int sensoresDetectando = 0;
  bool detectandoAnterior = false;

  for (int sensor = 0; sensor < NUMERO_SENSORES; sensor++) {
    if (valoresSensores[sensor] > umbralesCalibracionSensores[sensor]) {
      sensoresDetectando++;
    }
    // Realiza los cálculos para la posición
    sumaSensoresPonderados += (sensor + 1) * valoresSensores[sensor] * 1000L;
    sumaSensores += (long)valoresSensores[sensor];
  }

  // Comprueba el tiempo sin pista y se para automáticamente para evitar daños
  if (sensoresDetectando > 0 && sensoresDetectando < NUMERO_SENSORES) {
    ultimaLinea = millis();
  } else if (millis() > (ultimaLinea + TIEMPO_SIN_PISTA)) {
    competicionIniciada = false;
    set_color_RGB(0, 0, 0);
    pausa_timer_PID();
  }
  int pos;
  if (sensoresDetectando > 0) {
    pos = ((sumaSensoresPonderados / sumaSensores) - (NUMERO_SENSORES + 1) * (float)(1000 / 2));
  } else {
    pos = (ultimaPosicion > 0) ? (1000 * (NUMERO_SENSORES + 1) / 2) : -(1000 * (NUMERO_SENSORES + 1) / 2);
  }
  return map(pos, -6500, 6500, -1000, 1000);
}

/**
 * Función para calcular la corrección a aplicar a los motores para mantenerse en la posición deseada de la pista.
 * @param  posicionActual Posición actual sobre la pista.
 * @return [int]          Corrección que se debe aplicar al control de la velocidad.
 */
int calcular_PID(int posicionActual) {
  float p = 0;
  float i = 0;
  float d = 0;
  int error = 0;
  error = posicionIdeal - posicionActual;

  p = kp * error;
  if (error < 100) {
    integralErrores += error;
    i = ki * integralErrores;
  } else {
    i = 0;
    integralErrores = 0;
  }
  d = kd * (error - errorAnterior);
  errorAnterior = error;
  return p + i + d;
}

/**
 * Función para asignar velocidad a los motores teniendo en cuenta la corrección calculada por el PID
 * @param correccion Parámetro calculado por el PID para seguir la posición deseada en la pista
 */
void dar_velocidad(int correccion) {
  if (velocidad > 200) {
    velocidad = 200;
    set_color_RGB(0, 0, 255);
  }
  int velocidadIzquierda = velocidad;
  int velocidadDerecha = velocidad;
  if (!timerPID_pause) {
    velocidadIzquierda = velocidadIzquierda - correccion;
    velocidadDerecha = velocidadDerecha + correccion;
  }

  int MOTOR_DERECHO_ADELANTE_STATE = HIGH;
  int MOTOR_DERECHO_ATRAS_STATE = LOW;
  int MOTOR_IZQUIERDO_ADELANTE_STATE = HIGH;
  int MOTOR_IZQUIERDO_ATRAS_STATE = LOW;

  if (velocidadDerecha > velocidadMaxima) {
    velocidadDerecha = velocidadMaxima;
  } else if (velocidadDerecha < 0) {
    velocidadDerecha = abs(velocidadDerecha);
    if (velocidadDerecha > velocidadMaxima) {
      velocidadDerecha = velocidadMaxima;
    }
    MOTOR_DERECHO_ADELANTE_STATE = LOW;
    MOTOR_DERECHO_ATRAS_STATE = HIGH;
  }
  if (velocidadIzquierda > velocidadMaxima) {
    velocidadIzquierda = velocidadMaxima;
  } else if (velocidadIzquierda < 0) {
    velocidadIzquierda = abs(velocidadIzquierda);
    if (velocidadIzquierda > velocidadMaxima) {
      velocidadIzquierda = velocidadMaxima;
    }
    MOTOR_IZQUIERDO_ADELANTE_STATE = LOW;
    MOTOR_IZQUIERDO_ATRAS_STATE = HIGH;
  }

  digitalWrite(MOTOR_DERECHO_ADELANTE, MOTOR_DERECHO_ADELANTE_STATE);
  digitalWrite(MOTOR_DERECHO_ATRAS, MOTOR_DERECHO_ATRAS_STATE);
  digitalWrite(MOTOR_IZQUIERDO_ADELANTE, MOTOR_IZQUIERDO_ADELANTE_STATE);
  digitalWrite(MOTOR_IZQUIERDO_ATRAS, MOTOR_IZQUIERDO_ATRAS_STATE);

  analogWrite(MOTOR_DERECHO_PWM, velocidadDerecha);
  analogWrite(MOTOR_IZQUIERDO_PWM, velocidadIzquierda);
}

/**
 * Función de interrupción para el canal A del encoder derecho
 */
void encoder_derecho_A() {
  if (digitalRead(MOTOR_DERECHO_ENCODER_A)) {
    if (!digitalRead(MOTOR_DERECHO_ENCODER_B)) {
      ticksDerecho++;
    } else {
      ticksDerecho--;
    }
  } else {
    if (!digitalRead(MOTOR_DERECHO_ENCODER_B)) {
      ticksDerecho--;
    } else {
      ticksDerecho++;
    }
  }
}
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

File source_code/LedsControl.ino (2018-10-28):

/**
 * Función para aplicar un Rainbow al led RGB de la placa principal
 * @param [int] intervalo Tiempo en ms que transcurre entre cambios de color
 */
void set_rainbow_color(int intervalo) {
  if (millis() - ultimoCambioRGB > intervalo) {
    colorRGB[colorDesc] -= 3;
    colorRGB[colorAsc] += 3;
    set_color_RGB(colorRGB[0], colorRGB[1], colorRGB[2]);
    if (colorRGB[colorDesc] <= 0 || colorRGB[colorAsc] >= 255) {
      colorRGB[colorDesc] = 0;
      colorRGB[colorAsc] = 255;
      set_color_RGB(colorRGB[0], colorRGB[1], colorRGB[2]);
      colorDesc++;
      if (colorDesc > 2) {
        colorDesc = 0;
      }
      colorAsc = colorDesc == 2 ? 0 : colorDesc + 1;
    }
    ultimoCambioRGB = millis();
  }
}

/**
 * Función para establecer el valor de cada color del led RGB de la placa principal
 * @param r [int] Color Rojo 0-255
 * @param g [int] Color Verde 0-255
 * @param b [int] Color Azul 0-255
 */
void set_color_RGB(int r, int g, int b) {
  analogWrite(RED_RGB_R, r);
  analogWrite(RED_RGB_G, g);
  analogWrite(RED_RGB_B, b);
}

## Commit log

2017-10-01 Añade funciones iniciales de inicialización.
2017-10-01 Añade inicialización de motores.
2017-10-01 Añade librería I2C; Wire
2017-10-01 Añade librería sensores láser; VL53L0X
2017-10-01 Añade inicialización de sensores láser VL53L0X
2017-10-01 Añade inicialización de sensores QRE1113
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2017-10-02 Fix inicialización de Puerto Serial
    [Init.ino]
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2017-10-08 Añade funciones principales de calibrado de sensores de línea
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2017-10-29 Corrige error en calibrado de sensores de línea.
    [Lecturas.ino]
2017-10-29 Añade cálculo de posición para circuitos de línea.
2017-11-07 Añade librería PIDfromBT para calibración de PID a distancia.
2017-11-07 Corrige pines de los motores
    [Main.ino]
2017-11-07 Establece umbrales para límite de blanco-negro de los sensores de línea
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2017-11-07 Añade función para cálculo de la posición del robot sobre la línea.
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2017-11-12 Añade función de cálculo de la corrección mediante PID
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2017-11-12 Añade función de manejo de velocidades de los motores.
2017-11-12 Añade comprobaciones de parada de emergencia, en caso de perder la línea
2017-11-12 Añade mecanismo de arranque y configuraciones iniciales de competición.
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2017-11-14 Modifica la asignación de velocidades para evitar marcha atrás.
2017-11-17 Corrige pines de sensores láser
    [Main.ino]
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2017-11-17 Corrige lectura escalada de sensores de línea.
    [Lecturas.ino]
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2017-11-18 Añade funcion para saber si un sensor está dentro del degradado.
2017-11-18 Añade check de sensores en degradado para mantener posición al perderlo
2017-11-18 Añade librería ATDelay para controlar ejecuciones periodicas facilmente.
2017-11-18 Indenta el fichero correctamente.
2017-11-18 Añade función para realuzar un cambio ideal progresivo.
2017-11-18 Añade un filtrado para suavizar los cambios en el ideal.
2017-11-18 Fuerza el apagado de led para cuando no se realiza calibración.
2017-11-19 Baja los timeout de los sensores láser e inicia el frontal como continuo
2017-11-19 Actualiza la función de lectura de sensores láser.
2017-11-19 Establece el ideal inicial como la posición en la que inicia.
2017-11-19 Añade ATDelay para controlar el tiempo entre cada lectura frontal
2017-11-19 Añade variable sin uso para evitar cambios de ideal desde la APP de PID
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2017-11-19 Ajusta los filtros de posición y cambio de ideal
2017-11-19 Añade uso de función de comprobación de sensores láser.
2017-11-19 Añade llamada a función de cambio progresivo de ideal.
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2017-11-19 Añade apagado de led al finalizar cambio de ideal.
2017-11-19 Cambia orden de reseteo de ATDelay
    [Lecturas.ino]
2017-11-22 Mejora lógica de cambio de lado, permitiendo cambiar solo en rectas.
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2018-03-13 Añade funciones básicas para control de leds (RGB)
2018-03-13 Añade funciones principales de lectura de sensores de pista
2018-03-13 Añade funciones principales para el calibrado de los sensores de pista
2018-03-13 Añade funciones básicas de control: Cálculo posición, PID y Velocidades
2018-03-13 Corrige lecturas mapeadas de los sensores de pista
    [Lecturas.ino]
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2018-03-15 Ajusta los valores de saturación de sensores y posición
2018-03-15 Corrige lectura de botón a logica positiva
    [Lecturas.ino]
2018-03-15 Corrige lecturas de línea a lógica positiva
    [Lecturas.ino]
2018-03-15 Añade configuración de Timer1 para cálculo de posición y PID
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2018-03-16 Añade módulo de arranque para carreras; 5s para iniciar
2018-03-16 Añade control de velocidad a la función del Timer para sincronizarlo
2018-03-17 Añade configuración del Timer3 para ajustes via Serial-BT
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2018-03-20 Añade configuración para el ESC del Brushless de succión
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2018-03-22 Ajusta el tiempo sin pista para parada de emergencia en competición
2018-03-22 Añade cálculo de velocidad en m/s usando encoders
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2018-03-23 Añade parada de emergencia si todos los sensores detectan línea
2018-03-23 Añade función incial de detección de curvas y rectas por encoders
2018-03-23 Añade valores PIDV para pruebas en modo competición
2018-03-23 Imprime el valor de la bateria al pulsar el botón
2018-03-24 Corrige fallo en parada de emergencia
    [Control.ino]
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2018-03-28 Implementa mapeo de circuito para acelerar en rectas
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2018-03-29 Gestiona Brushless mediante Timer para evitar incompatibilidades con PID
    [Init.ino, Main.ino, Timers.ino]
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2018-03-29 Soluciona problema de conteo de ticks en cuadratura
    [Control.ino, Init.ino, Main.ino]
2018-03-29 Añade funciones de pausa y reanudado de Timers
2018-03-30 Añade menú de ajustes para la cruceta de botones
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2018-03-31 Corrige condiciones para realizar mapeo de circuito
    [Timers.ino]
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2018-03-31 Corrige mapeo de pista; reseteo de ticks
    [Control.ino, Main.ino]
2018-04-09 Soluciona bug en saturación de sensores
    [Lecturas.ino]
2018-04-09 Añade control de distancia frontal con otros robots
2018-04-09 Aumenta valor de saturación baja para sensores de pista
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2018-04-11 Mueve el calibrado de sensores a los botones izquierdo-derecho
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2018-04-13 Cambia todos los `velocidadBase` por `velocidad` para config en menú
2018-04-13 Cambia el uso de las constantes del PID para configurar mediante menú
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2018-04-24 Corrige saturación en la lectura
    [Lecturas.ino]
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2018-05-16 Añade check en calibración de línea para guardar un tracking de posición
2018-05-16 Añade margen del 75% en el estado de batería
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2018-06-03 Ajusta el PID para evitar oscilaciones en Degradado
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2018-06-03 Ajusta asignación de correcciones cuando esté el robot en movimiento
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2018-06-03 Añade functión de lectura digital para el multiplexador
2018-06-03 Corrige almacenado de valores raw
    [Lecturas.ino]
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2018-06-03 Añade variables de control y mejora el sistema de inicio del robot
2018-06-03 Separa en función la busqueda de línea principal
2018-06-06 Corrige secuencia de inicio
    [Main.ino]
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2018-07-12 Corrige valores de medición de batería
    [Control.ino]
2018-07-12 Mejora indicadores LED de batería y configuración Brushless
2018-09-28 Actualiza calibración, control de línea y varias mejoras
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2018-10-27 Añade nuevo menú de Velocidades y segundo arranque
2018-10-28 Elimina código no usado y mejora control de motores
2019-09-15 Añade diseño de PCBs
    [DragonBot.kicad_pcb, DragonBot.sch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]
2019-09-15 Añade ficheros stl
    [DragonBot_Base_Motores.stl, DragonBot_Caja_FTDI_Base.stl, DragonBot_Caja_FTDI_Tapa.stl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]
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2023-05-01 Actualiza README y reorganiza ficheros
    [DragonBot_Base_Motores.stl, DragonBot_Caja_FTDI_Base.stl, DragonBot_Caja_FTDI_Tapa.stl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]
